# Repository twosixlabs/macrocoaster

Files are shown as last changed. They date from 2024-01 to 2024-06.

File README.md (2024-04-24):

# Macrocoaster

Thank you for picking up a macrocoaster from TwoSix Technologies!

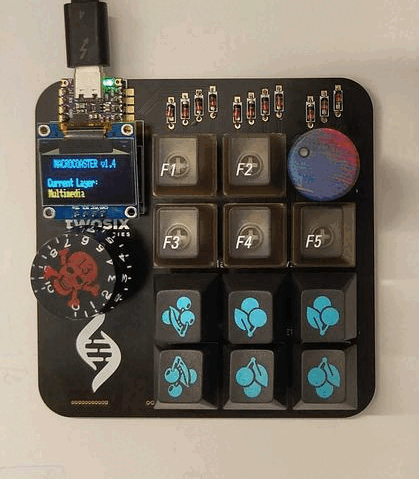
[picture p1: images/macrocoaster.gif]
GIF of spinning knob changing the layers


If you weren't able to pick one up in person, [this repo](./hardware/PCB/) contains mainufacturing files to order your own board (through JLCPCB, PCBWAY, etc.)

## Why this?
We wanted to give you something useful, fun, and memorable, whether it's a neat circuit board coaster, a fun beginner-friendly soldering kit, or a powerful productivity tool :)

## Usage
The Macrocoaster has two main uses: as a coaster, and as a macropad!
### Coaster:
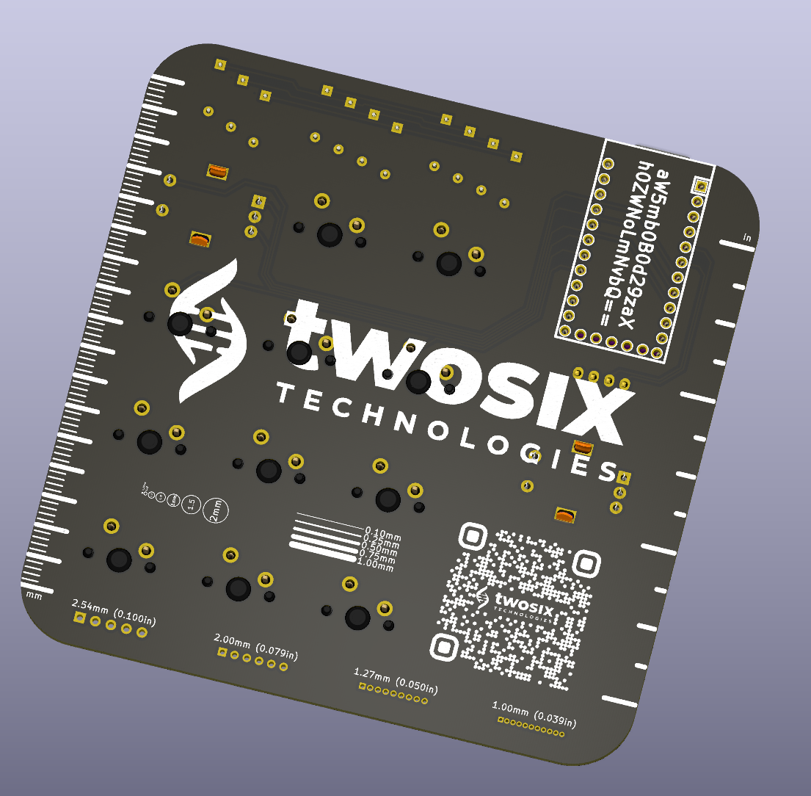
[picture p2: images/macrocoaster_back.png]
back of board


* Coaster 👍
### Macropad:
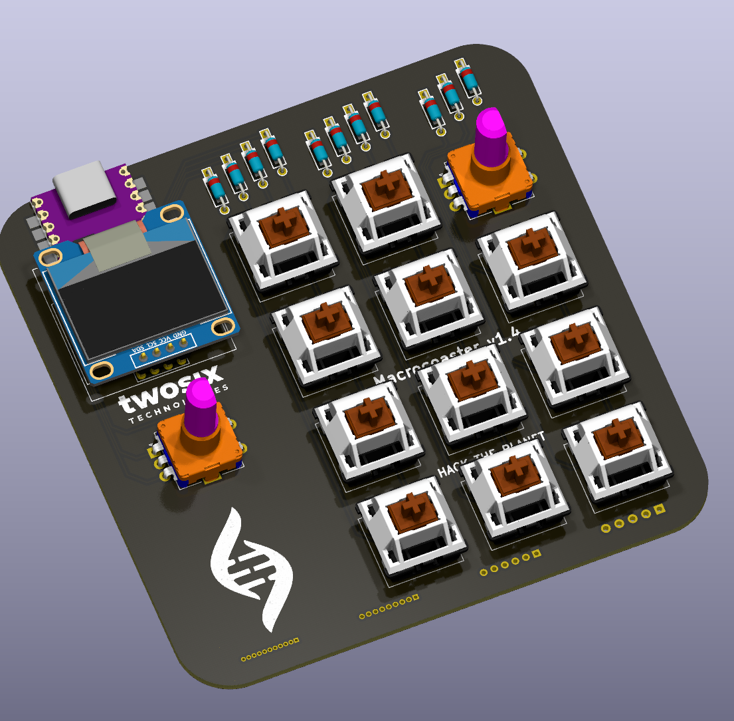
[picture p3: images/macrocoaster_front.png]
front of board
 

* A "macropad" is a (usually) small keyboard used to add functionality to or automate your regular keyboard. Each key's function is programmable, so on a press it can type entire paragraphs, change your computer volume, or hit a combination of keys together. 

* The macrocoaster is unique in that there is a knob that lets you scroll through [layers](https://keebmaker.com/pages/layers), allowing for "pages" of macro keys, instead of just 11. You can think of this like how your SHIFT key changes certain keyboard keys to something else, but instead of one modifier key (SHIFT), you have a dial!

## Feature Overview
### Hardware
* Ruler
    * Inch and mm ruler
    * Common trace widths
    * Common hole diameters
* Header references
    * Common header pitches for reference
* Cross-microcontroller compatibility
    * The macrocoaster board can use an [Arduino Pro Micro](https://www.aliexpress.us/item/3256805735375493.html), [Elite-C](https://www.boardsource.xyz/products/Elite-C_v4), [kb2040](https://www.adafruit.com/product/5302) or any other pro-micro-esque footprint board [supported by QMK](https://github.com/qmk/qmk_firmware/blob/master/docs/compatible_microcontrollers.md)
* ENIG finish - there's gold on this board! 😱
### Software
* Scrollable layers
    * The left rotary encoder scrolls through defined keyboard layers (displayed on the OLED) for a theoretical maximum of (32 layers) * (11 keys) = *_352_ custom macro keys*!
* Bindable rotary encoder
    * By default, the right rotary encoder functions as a volume knob, but can be rebound to send any keycode! (for example, scrolling the grid size in KiCAD)
* Caps-lock indicator via OLED

## BoM (Bill of Materials)
See the [interactive BoM](https://htmlpreview.github.io/?https://github.com/twosixlabs/macrocoaster/blob/main/hardware/BoM/ibom.html) :)
<!-- Note: Update link to future repo! -->

#### Required:
* Microcontroller (see [above](#hardware))
* Any full-size [Cherry MX](https://www.keychron.com/blogs/news/cherry-mechanical-switch-guide) style [keyswitches](https://www.theremingoat.com/blog/beginners-guide) work 
    * Personally, [these](https://drop.com/buy/everglide-oreo-mechanical-switches) and [these](https://divinikey.com/products/lelelab-y2k-tactile-switches) are my favorite
* I recommend [EC-11 style rotary encoders](https://www.amazon.com/uxcell-Degree-Encoder-Digital-Potentiometer/dp/B07R8JPM6D)
* I used [these diodes](https://www.amazon.com/BOJACK-Switching-IN4148-Electronic-Silicon/dp/B07Q4F3Y5W)
* Any 128x64 `SSD1306` OLED breakout with a `[GND, Vcc, SCL, SDA]` pinout works
    * I used [these](https://www.amazon.com/Hosyond-Display-Self-Luminous-Compatible-Raspberry/dp/B09C5K91H7) as the yellow lines make the layer name stand out nicely :D

#### Optional: (but highly recommended)
* Keycaps
    * Entirely your preference :)
        * [This site](https://kbdfans.com/collections/keycaps) is a great starting point
            * Check if there is a "numpad" set, if you don't want the whole keyboard
            * Sites such as [this](https://www.wasdkeyboards.com/products/keycaps/blank-keycap-singles.html) offer per-key pricing, some other sites can even print custom designs on keys!
* Rotary encoder knobs
    * There are many, many [options](https://www.amazon.com/s?k=potentiometer+knob), just make sure they fit your encoder shaft (some are semi-circles, some have knurling, etc.)
* [Rubber "feet"](https://www.amazon.com/s?k=rubber+feet)
    * This keeps the bottom of the board (with the solder blobs/THT components) from scratching up or shorting on whatever surface you have.

## Assembly
1. Liberally apply flux to the back of the board (the side with all the graphics)
2. Place your key switches (`SW1` - `SW11`) in (on the side without the rules), and solder them
3. Diodes (technically optional, if you don't care about [ghosting](https://pcbheaven.com/wikipages/How_Key_Matrices_Works/))
    * If using diodes, solder down `D1` - `D11` (in any order). Make sure the polarity is correct.
    * If not using diodes, short `D1` - `D11` with solder, wires, or leads
4. Solder both rotary encoders (`SW13`, `SW14`)
5. Solder down your controller
    * You can use the castellated pads if your controller has them, or simply use traditional headers
6. Head down to the [Programming guide](#programming) before soldering the OLED
7. Apply some kapton (or other non-conductive tape) to the bottom of the OLED
    * This prevents the OLED from shorting microcontroller pins
8. Solder down the OLED so it covers your controller
    * Note: if using headers (instead of castellated pads) to solder down your controller, you made need [tall headers](https://www.amazon.com/HiLetgo-20pcs-2-54mm-Single-Header/dp/B07R5QDL8D) or [female headers](https://www.amazon.com/Glarks-Connector-Assortment-Stackable-Breakaway/dp/B07CWSXY7P) to clear the board.
        * In the case of the kb2040, the stemma connector causes the OLED to sit at a bit of an angle, which personally I find kind of convenient.

## Programming
1. Install `qmk`
    * [QMK install guide](https://docs.qmk.fm/#/newbs_building_firmware)
        * Note: Merging the macrocoaster into qmk is underway.
        * For now
          * Define a new keyboard `qmk new-keyboard`
          * Choose last option `none of the above`
          * Choose your chip, although it doesn't matter. I selected `kb2040`
2. Download the code
    * `git clone https://github.com/twosixtech/macrocoaster && cd macrocoaster/firmware`
3. Compile and flash for your microcontroller
    * You will need to press the Flash/boot/etc. button down when loading the code for the first time (QMK will prompt you ) 
        * All later flashes can be done with the [magic-bootloader](https://github.com/qmk/qmk_firmware/blob/master/docs/feature_bootmagic.md) key :)
     * delete everything in the macrocoaster dir defined with `qmk new-keyboard` above
     * copy   `macrocoaster/firmware` into your qmk home dir and difined firmware for macrocoaster `qmk_firmware/keyboards/macrocoaster`. Like this `cp -r * ~/qmk_firmware/keyboards/macrocoaster` or similar.
    * Elite-C/Pro-micro
        * `qmk compile -kb macrocoaster -km default && qmk flash -bl dfu -km default -kb macrocoaster`
    * kb2040
        * `qmk compile -kb macrocoaster -km default && qmk flash -km default -kb macrocoaster -e CONVERT_TO=kb2040`

## Macropad Usage
By default, the macropad comes with (roughly) [this layout](./firmware/keymaps/default/keymap.c):
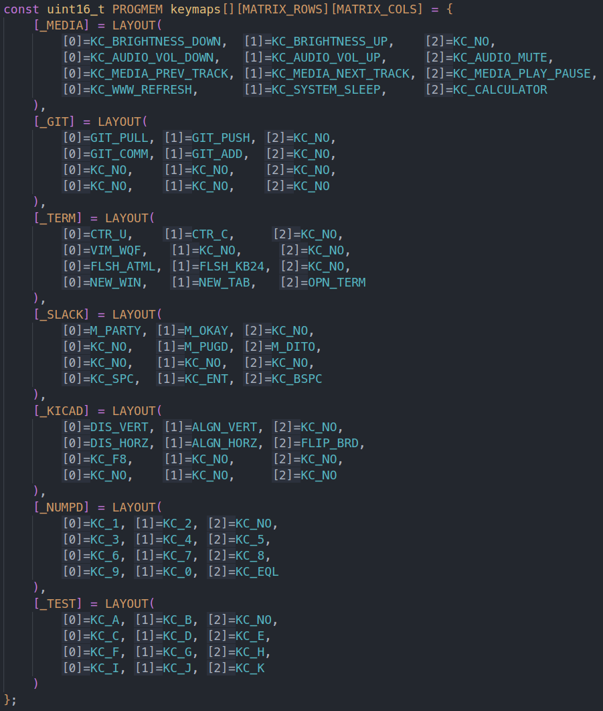
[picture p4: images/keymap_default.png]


# Notes
To put the KB2040 into programming mode, with the USB port oriented up, hold the bottom left button down, and then press the right and release the left. As documented [here](https://golem.hu/guide/kmk-firmware/)

## Customization (WIP)
Almost all customization will be done in the [`keymap.c`](./firmware/keymaps/default/keymap.c) file.

See the [QMK docs](https://docs.qmk.fm/#/) and [QMK code](https://github.com/qmk/qmk_firmware/blob/master/docs/) for instructions/guidance, as well as the comments in `keymap.c`.
* If you toss the code, with its existing comments into ChatGPT, it does a pretty good job at helping explain :)

The bootloader can be entered by holding down the `SW4` key while the board is powered on
* Note: with the `kb2040`, entering the bootloader make take a few attempts (make sure to wait ~5s on each attempt)

_Note_: Unfortunately because of QMK is architected with macros and `#define`'s, values for things like layer #'s must be known at compile-time and not runtime, making things like automatically calculating the next/prev layer very difficult :(
For example, 
```
#define NUMBER_OF_LAYERS (sizeof(keymaps) / sizeof(keymaps[0]))

int get_next_layer(int currlayer) {
    return (currlayer + 1) % NUMBER_OF_LAYERS;
}
int get_prev_layer(int currlayer) {
    return (currlayer - 1 + NUMBER_OF_LAYERS) % NUMBER_OF_LAYERS;
}
```
is not possible. :pensive_cowboy:</a>

## Cases
STL/3MF files for 3D-printable cases can be found in the [cases](./hardware/Cases) folder :)

## Builds
If you feel inclined, it would be amazing if if/after you complete a macrocoaster build, you post it in the [builds](./builds) folder! I posted [my build(s)](./builds/Engineer-2) there, feel free to copy that folder and use it as a template :)

If you want to share your build, please open a PR with your setup in its own subfolder in the builds folder!

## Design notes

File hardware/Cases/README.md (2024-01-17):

# Cases

Hey! This folder should contain subfolders for different case designs :)
Please feel free to PR and add any if you want!

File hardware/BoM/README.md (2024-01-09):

See [this link](https://htmlpreview.github.io/?https://github.com/twosixlabs/macrocoaster/blob/main/hardware/BoM/ibom.html) for a rendered version :)

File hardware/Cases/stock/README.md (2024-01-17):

## Stock

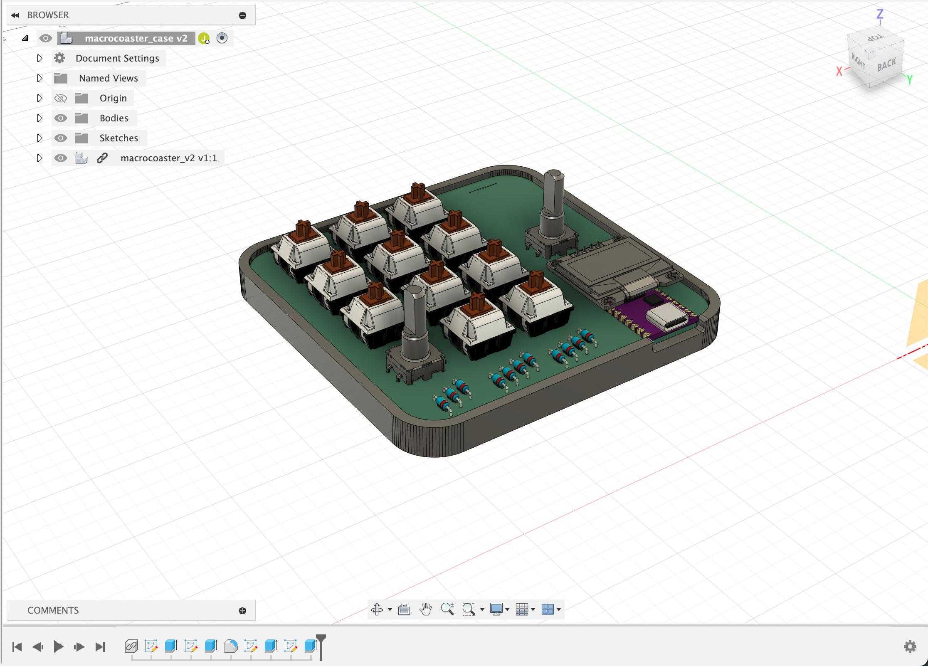
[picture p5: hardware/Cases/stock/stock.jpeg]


I have printed [this](./macrocoaster_case.3mf) in both TPU and PLA successfully :)

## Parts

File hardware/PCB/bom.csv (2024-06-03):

Designator | Footprint | Quantity | Value | LCSC Part #
Brd1 | 128x64OLED | 1 | SSD1306
D1, D10, D11, D2, D3, D4, D5, D6, D7, D8, D9 | D_SOD123_axial | 11 | D
SW1, SW10, SW11, SW2, SW3, SW4, SW5, SW6, SW7, SW8, SW9 | MX_PCB_1.00u | 11 | Switch
SW13, SW14 | RotaryEncoder_Alps_EC11E-Switch_Vertical_H20mm | 2 | RotaryEncoder_Switch
U1 | Elite-C-castellated-29pin-holes | 1 | Elite-C

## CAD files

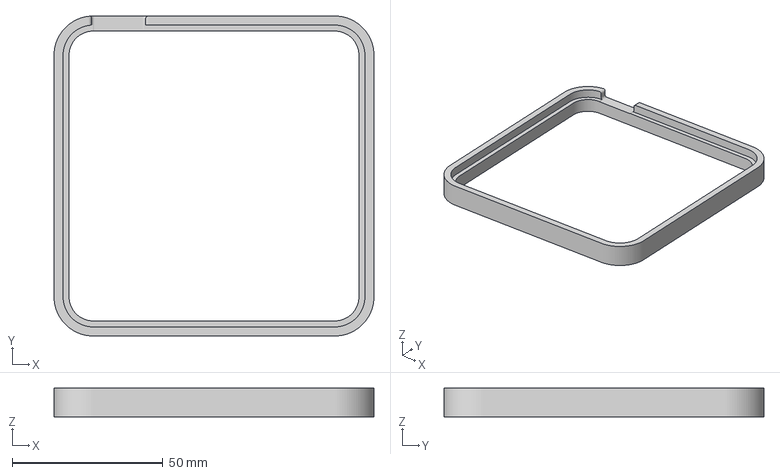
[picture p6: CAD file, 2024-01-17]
hardware/Cases/stock/macrocoaster_case.3mf
106.0 x 106.0 x 9.50 mm

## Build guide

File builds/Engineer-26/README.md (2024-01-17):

## My Macrocoaster Build

### Info
Hey all! These are my personal macrocoasters I use :)

### BoM
I use both an elite-c and kb2040 based macrocoaster, with the BoM described in the main README.md hahaha

### Pics
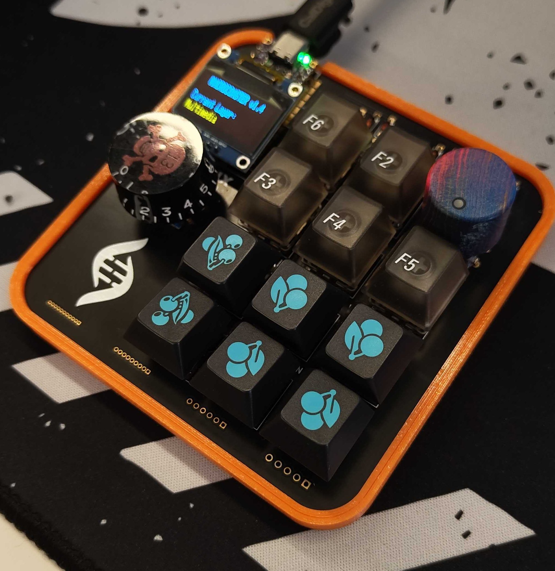
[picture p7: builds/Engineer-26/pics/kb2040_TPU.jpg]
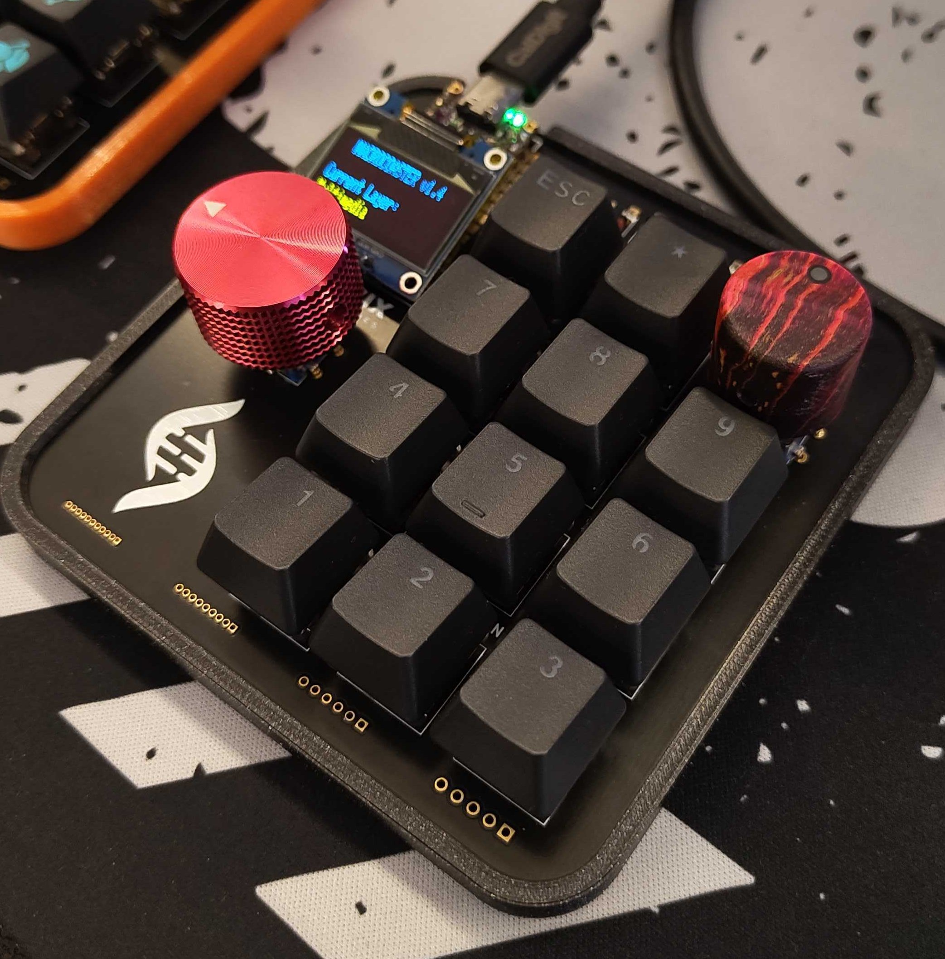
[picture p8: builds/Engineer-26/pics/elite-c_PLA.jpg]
  

I primarily use my kb2040 based board, but keep an  elite-c based one on my desk as well to make sure the firmware works on both!

The kb2040 based one has the skull guitar knob on it, as features the case printed in TPU (a semi-flexible filament) which helps insulate the board and sounds nice :)

The Elite-C based one has the frame printed in PLA for simplicity.

If anyone is curious, there were several dev board versions, this is the whole family:

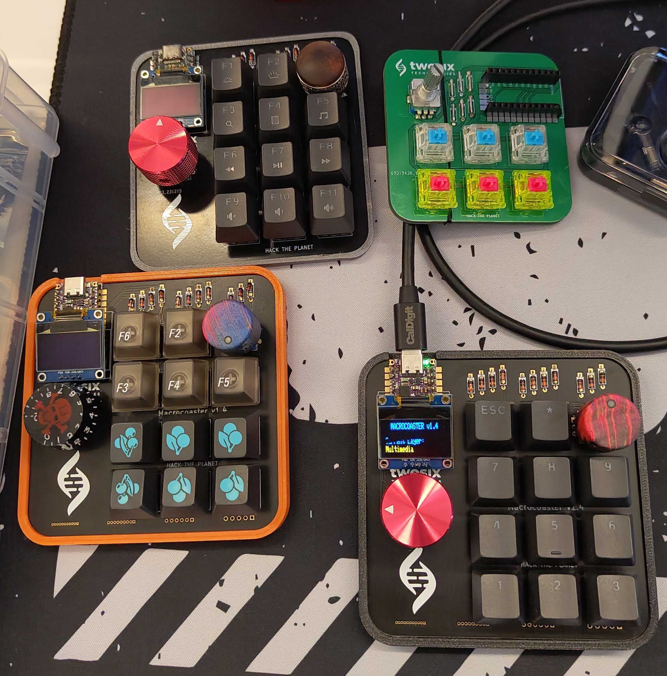
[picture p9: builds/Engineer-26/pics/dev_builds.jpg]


### Customizations/changes
Running stock firmware and hardware ;)

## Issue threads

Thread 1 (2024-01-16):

Builds

bamhm182, 2024-01-16:
This isn't an issue, but I thought it would be fun to have a place to talk about/show off our builds of this macropad. I picked up the PCB from Shmoocon 24 and liked the idea. I've also been wanting to mess with a bluetooth QMK enabled keypad for a while, so I figured I'd finally get around to trying it out. I bought the required parts for $32.83 on AliExpress and will post back with pictures when I get everything in.

- 11x [Keycaps](https://www.aliexpress.us/item/3256805859712981.html) ($7.60)
- 100x [DO-35 1N4148 Diodes](https://www.aliexpress.us/item/3256805940754058.html) ($1.38)
- 1x [NRF52840 Bluetooth Controller](https://www.aliexpress.us/item/3256806085566324.html) ($9.31)
- 30x [Outemu Brown Switches](https://www.aliexpress.com/item/3256805690299829.html) ($3.72)
- 1x [301230 110mAh battery](https://www.aliexpress.com/item/2251832546143327.html) ($5.48)
- 1x [0.96" OLED SPI/I2C screen](https://www.aliexpress.com/item/3256805849070952.html) ($1.70)
- 5x [EC11 Rotary Encoders & knobs](https://www.aliexpress.com/item/3256805796819763.html) ($3.64)

If you're reading this and have beat me to a build, post your pictures!

Engineer-26, 2024-01-17:
Thank you so much! It would genuinely make my day to see people build some of these!

I'll set up a folder for builds so that people can PR their setups and pictures in :)

Engineer-26, 2024-01-17:
(Closing this so I can track open issues, but please feel free to keep posting here!

Engineer-26, 2024-01-17:
check out [the builds folder](https://github.com/twosixlabs/macrocoaster/builds/) :) We'd love to see yours there!

bamhm182, 2024-01-17:
Awesome! I'll definitely submit a PR when I get mine done. That's also a good solution!

Side note, can we get the stl for you macrocoaster-coaster? (The frame)

Engineer-26, 2024-01-17:
absolutely! I posted it [here](https://github.com/twosixlabs/macrocoaster/tree/main/hardware/Cases/), ill add some new/better ones soon too :)

bamhm182, 2024-01-29:
I started getting my parts in! Still 2 more deliveries, but all of the parts I need to get it working at a base level are in. Going to see if I can find time to get it working before the keycaps and encoders come in. Super excited!

Engineer-26, 2024-02-02:
looking forward to it as well! 🥳🥳🥳

bamhm182, 2024-02-06:
Programming hand the writeup are going to have to wait until another day, but I finally found time to assemble it.
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

Closed 2024-01-17.

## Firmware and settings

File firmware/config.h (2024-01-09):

// Copyright 2023 placeholder (@placeholder)
// SPDX-License-Identifier: GPL-2.0-or-later

#pragma once

/*
 * Feature disable options
 *  These options are also useful to firmware size reduction.
 */

/* disable debug print */
//#define NO_DEBUG

/* disable print */
//#define NO_PRINT

/* disable action features */
//#define NO_ACTION_LAYER
//#define NO_ACTION_TAPPING
//#define NO_ACTION_ONESHOT

#define ENCODERS_PAD_A { B4, D7 }
#define ENCODERS_PAD_B { E6, C6 }
#define ENCODER_RESOLUTION 4
#define DIP_SWITCH_PINS { D4, B5 }

#define BOOTMAGIC_LITE_ROW 1
#define BOOTMAGIC_LITE_COLUMN 1

#define OLED_TIMEOUT 60000
// #define OLED_SCROLL_TIMEOUT 5000
#define OLED_FADE_OUT
#define OLED_FADE_OUT_INTERVAL 10
// #define OLED_DISPLAY_128X64

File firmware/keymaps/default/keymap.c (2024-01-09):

// Copyright 2023 QMK
// SPDX-License-Identifier: GPL-2.0-or-later

#include "keycodes.h"
#include "oled_driver.h"
#include QMK_KEYBOARD_H

#define _MEDIA 0
#define _GIT 1
#define _TERM 2
#define _SLACK 3
#define _KICAD 4
#define _NUMPD 5
#define _TEST 6

enum custom_keycodes {
    M_HELLO = SAFE_RANGE,
    M_PARTY,
    M_OKAY,
    M_DITO,
    M_PUGD,

    DIS_VERT,
    DIS_HORZ,
    ALGN_VERT,
    ALGN_HORZ,
    FLIP_BRD,

    GIT_PULL,
    GIT_PUSH,
    GIT_COMM,
    GIT_SEND,
    GIT_ADD,

    VIM_WQF,
    CTR_C,
    CTR_U,
    NEW_WIN,
    NEW_TAB,
    OPN_TERM,

    FLSH_ATML,
    FLSH_KB24
};

// CUSTOM MACROS DEFINED HERE
// Make sure to add to custom_keycodes enum, and use in keymap
// https://docs.qmk.fm/#/feature_macros?id=using-macros-in-c-keymaps
bool process_record_user(uint16_t keycode, keyrecord_t *record) {
    switch (keycode) {
        case M_HELLO:
            if (record->event.pressed) {
                SEND_STRING("# Hello world!\n");
            } // add else for on release
            break; // Don't forget this line!
        
        case M_PARTY:
            if (record->event.pressed) {
                SEND_STRING(":partyparrot:"SS_DELAY(100)"\n");
            }
            break;
        case M_OKAY:
            if (record->event.pressed) {
                SEND_STRING(":ok:"SS_DELAY(100)"\n");
            }
            break;
        case M_DITO:
            if (record->event.pressed) {
                SEND_STRING(":ditto_party:"SS_DELAY(100)"\n");
            }
            break;
        case M_PUGD:
            if (record->event.pressed) {
                SEND_STRING(":pug_dance_fast:"SS_DELAY(100)"\n");
            }
            break;

        case DIS_VERT:
            if (record->event.pressed) {
                SEND_STRING(";");
            }
            break;
        case DIS_HORZ:
            if (record->event.pressed) {
                SEND_STRING(".");
            }
            break;   
        case ALGN_VERT:
            if (record->event.pressed) {
                SEND_STRING("\"");
            }
            break;  
        case ALGN_HORZ:
            if (record->event.pressed) {
                SEND_STRING("?");
            }
            break;  
        case FLIP_BRD:
            if (record->event.pressed) {
                SEND_STRING("]");
            }
            break; 

        case GIT_PUSH:
            if (record->event.pressed) {
                SEND_STRING("git push\n");
            }
            break;
        case GIT_PULL:
            if (record->event.pressed) {
                SEND_STRING("git pull\n");
            }
            break;
        case GIT_COMM:
            if (record->event.pressed) {
                SEND_STRING("git commit -m \"\"" SS_TAP(X_LEFT));
            }
            break;
        case GIT_ADD:
            if (record->event.pressed) {
                SEND_STRING("git add -A\n");
            }
            break;

        case VIM_WQF:
            if (record->event.pressed) {

                SEND_STRING("\e:wq\n");
            }
            break;
        case CTR_C:
            if (record->event.pressed) {
                SEND_STRING(SS_LCTL("c"));
            }
            break;
        case CTR_U:
            if (record->event.pressed) {
                SEND_STRING(SS_LCTL("u"));
            }
            break;
        case NEW_WIN:
            if (record->event.pressed) {
                SEND_STRING(SS_LCTL("t"));
            }
            break;
        case NEW_TAB:
            if (record->event.pressed) {
                SEND_STRING(SS_LCTL("N"));
            }
            break;
        case OPN_TERM:
            if (record->event.pressed) {
                SEND_STRING(SS_LGUI() "terminal\n");
            }
            break;

        case FLSH_ATML:
            if (record->event.pressed) {
                // #if defined(QMK_MCU)
                //     #if (QMK_MCU == atmega32u4)
                //         SEND_STRING("qmk compile -kb macrocoaster -km default && qmk flash -bl dfu -km default -kb macrocoaster\n");
                //     #elif (QMK_MCU == asd)
                //         SEND_STRING("qmk compile -kb macrocoaster -km default && qmk flash -bl dfu -km default -kb macrocoaster -e CONVERT_TO=kb2040\n");
                //     #else
                //         SEND_STRING("# [FAIL] Unknown MCU detected\n");
                //     #endif
                // #endif
                SEND_STRING("qmk compile -kb macrocoaster -km default && qmk flash -bl dfu -km default -kb macrocoaster\n");
            }
            break;
        case FLSH_KB24:
            if (record->event.pressed) {
                SEND_STRING("qmk compile -kb macrocoaster -km default && qmk flash -km default -kb macrocoaster -e CONVERT_TO=kb2040\n");
            }
            break;
    
    }
    return true;
};


// Define keymaps here (either QMK keycodes or from process_record_user())
// See https://github.com/qmk/qmk_firmware/blob/master/docs/keycodes.md
/* 
    [_NAME] = LAYOUT(
        KC_A,   KC_B,   KC_NO, //the KC_NO switch doesn't exist (knob)
        KC_C,   KC_D,   KC_E,
        KC_F,   KC_G,   KC_H,
        KC_I,   KC_J,   KC_K
    )
*/
const uint16_t PROGMEM keymaps[][MATRIX_ROWS][MATRIX_COLS] = {
    [_MEDIA] = LAYOUT(
        KC_BRIGHTNESS_DOWN,  KC_BRIGHTNESS_UP,    KC_NO,
        KC_AUDIO_VOL_DOWN,   KC_AUDIO_VOL_UP,     KC_AUDIO_MUTE,
        KC_MEDIA_PREV_TRACK, KC_MEDIA_NEXT_TRACK, KC_MEDIA_PLAY_PAUSE,
        KC_WWW_REFRESH,      KC_SYSTEM_SLEEP,     KC_CALCULATOR
    ),
    [_GIT] = LAYOUT(
        GIT_PULL, GIT_PUSH, KC_NO,
        GIT_COMM, GIT_ADD,  KC_NO,
        KC_NO,    KC_NO,    KC_NO,
        KC_NO,    KC_NO,    KC_NO
    ),
    [_TERM] = LAYOUT(
        CTR_U,    CTR_C,     KC_NO,
        VIM_WQF,   KC_NO,     KC_NO,
        FLSH_ATML, FLSH_KB24, KC_NO,
        NEW_WIN,   NEW_TAB,   OPN_TERM
    ),
    [_SLACK] = LAYOUT(
        M_PARTY, M_OKAY, KC_NO,
        KC_NO,   M_PUGD, M_DITO,
        KC_NO,   KC_NO,  KC_NO,
        KC_SPC,  KC_ENT, KC_BSPC
    ),
    [_KICAD] = LAYOUT(
        DIS_VERT, ALGN_VERT, KC_NO,
        DIS_HORZ, ALGN_HORZ, FLIP_BRD,
        KC_F8,    KC_NO,     KC_NO,
        KC_NO,    KC_NO,     KC_NO
    ),
    [_NUMPD] = LAYOUT(
        KC_1, KC_2, KC_NO,
        KC_3, KC_4, KC_5,
        KC_6, KC_7, KC_8,
        KC_9, KC_0, KC_EQL
    ),
    [_TEST] = LAYOUT(
        KC_A, KC_B, KC_NO,
        KC_C, KC_D, KC_E,
        KC_F, KC_G, KC_H,
        KC_I, KC_J, KC_K
    )
};
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

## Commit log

2024-01-17 added builds and cases
    [macrocoaster_case.3mf]
2024-01-17 added case info
2024-06-03 updated kicad version
    [macrocoaster_v2.kicad_pcb, macrocoaster_v2.kicad_sch]
2024-06-03 Updated manufacturing files
    [bom.csv, designators.csv, positions.csv]
2024-06-03 updated PCB files
    [macrocoaster_v2-B_Cu.gbr, macrocoaster_v2-B_Mask.gbr, macrocoaster_v2-B_Paste.gbr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]
